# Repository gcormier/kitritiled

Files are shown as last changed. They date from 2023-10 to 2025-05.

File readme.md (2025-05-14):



# kitritiled
This is a copy of Ted Yapo's tritiled project from https://github.com/tedyapo/tritiled. It is based on the V3.1 design.
I did my best to reproduce the schematic, and optimize it for automated assembly as opposed to hand-assembly. As a result, it uses some slightly different parts, such as 0402 components when possible.

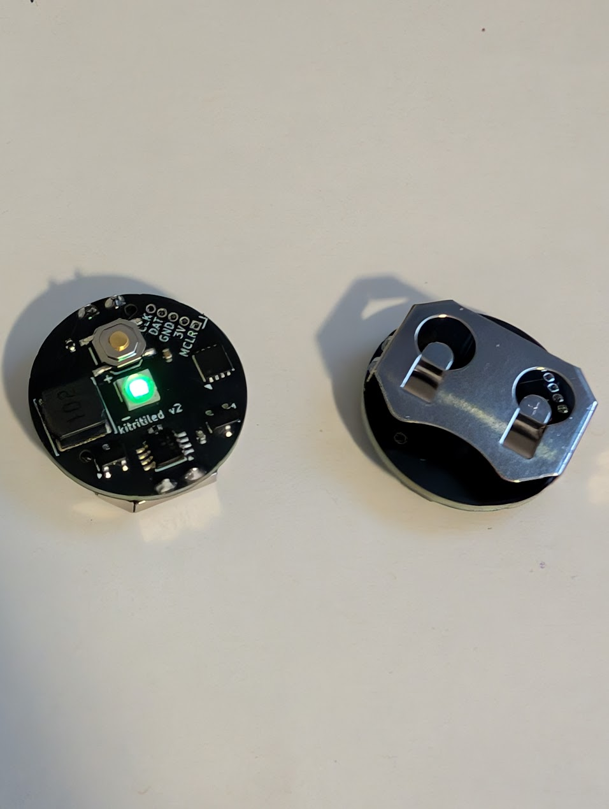
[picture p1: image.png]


## Firmware
kitritiled.hex is the firmware to flash. I lost track of the changes I made to the original firmware by Ted - if you use his v30 runtime selectable, it almost works, except the button doesn't seem to trigger the interrupt. It's been a few years since I looked at it, so I pulled the firmware off one of my v1 devices and
that's all I have unfortunately. `modes.h` is also changed slightly from his.

## Flashing
I use MPLAB IPE to flash the firmware with a MPLAB PICkit 5.

## Usage
The device has 10 power levels, and starts on the brightest setting.

When you first insert the battery, you have a 10 second window during which you can configure the power level.

This is done by pushing the button on the device. Once you hit the lowest power level, it will start back at the highest.

When you are done, leave it alone. It will blink the LED to indicate the power level. eg 1 blink for level 1, 2 blinks for level 2, etc.

It will do this three times, at which point it will then lock in at that power level and the button will no longer work.

If you want to change the power level, you need to remove the battery, and wait for the light to go out completely before repeating the above process.

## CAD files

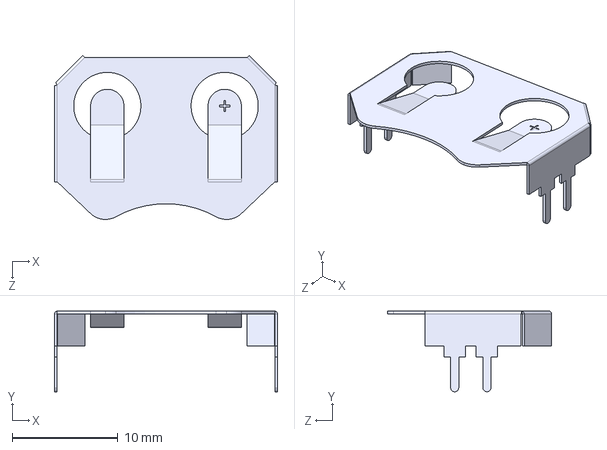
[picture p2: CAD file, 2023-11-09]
pcb/BAT-HLD-001-THM.step
21.1 x 7.62 x 15.5 mm

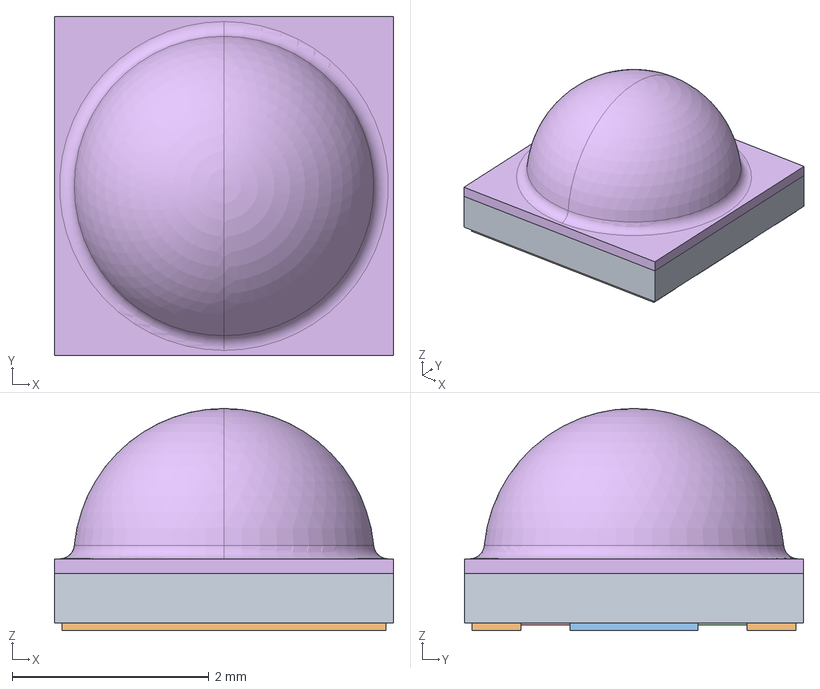
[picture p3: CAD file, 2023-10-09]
pcb/XLamp XP-E2 XP-G2.STEP
3.45 x 3.45 x 2.26 mm
2500-00565C
2500-00565C-BT
2500-00565C-SBN
2500-00565C-SB
2610-00066-DOME

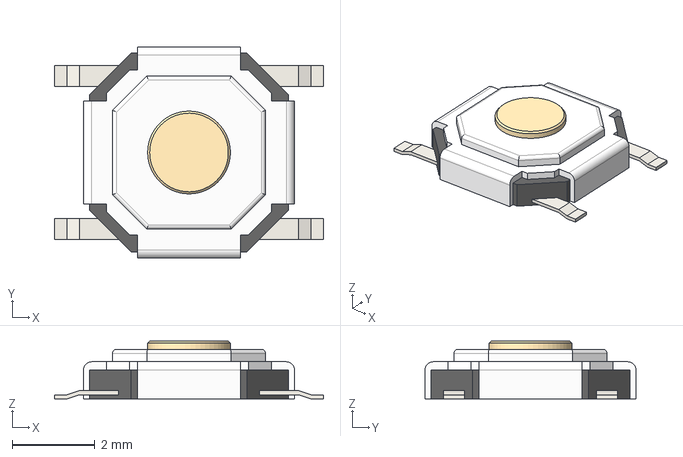
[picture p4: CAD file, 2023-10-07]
pcb/TS-1187A.step
6.50 x 5.10 x 1.40 mm

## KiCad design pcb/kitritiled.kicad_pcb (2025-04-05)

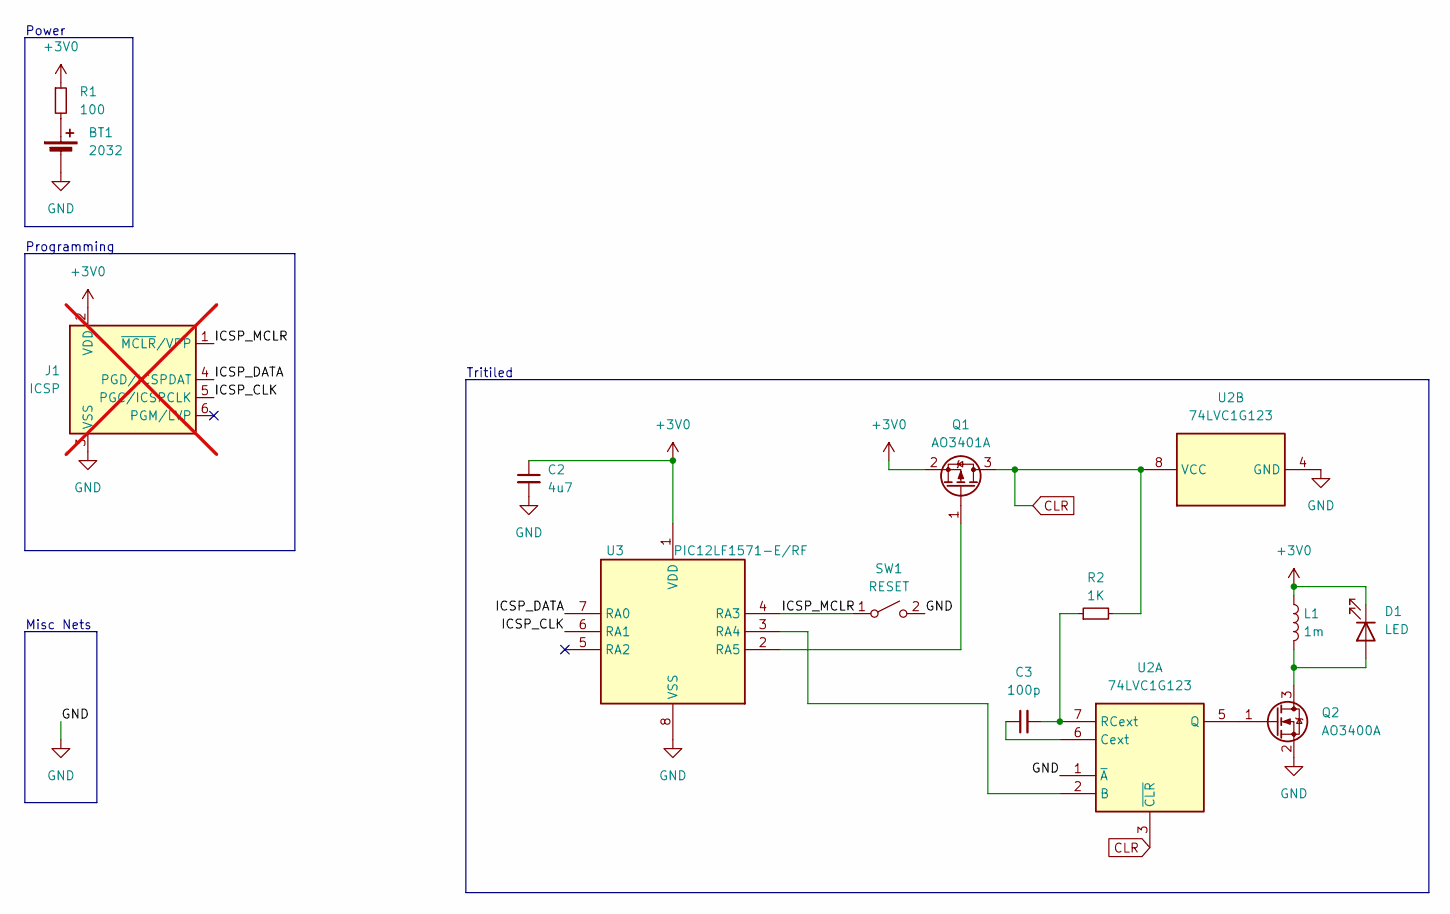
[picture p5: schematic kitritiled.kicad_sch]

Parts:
BT1: 2032; BAT_BAT-HLD-001-THM
C2: 4u7; C_0402_1005Metric; LCSC C23733
C3: 100p; C_0402_1005Metric; LCSC C1546
D1: LED; LED_Cree-XP; DIGIKEY XPEBGR-L1-0000-00F02
J1: ICSP; PinHeader_1x05_P1.27mm_Vertical; not fitted
L1: 1m; L_Sunlord_SWPA6028S; LCSC C133757
Q1: AO3401A; SOT-23; LCSC C15127
Q2: AO3400A; SOT-23; LCSC C20917
R1: 100; R_0402_1005Metric; LCSC C25076
R2: 1K; R_0402_1005Metric; LCSC C11702
SW1: RESET; SW_Push_1P1T_XKB_TS-1187A; LCSC C318884
U2: 74LVC1G123; TSSOP-8_3x3mm_P0.65mm; LCSC C513291
U3: PIC12LF1571-E/RF; DFN-8-1EP_3x3mm_P0.65mm_EP1.55x2.4mm; LCSC C635312

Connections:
+3V0: C2.1, D1.1 (K), J1.2 (VDD), L1.1, Q1.2 (S), R1.1, U3.1 (VDD)
/ICSP_CLK: J1.5 (PGC/ICSPCLK), U3.6 (RA1)
/ICSP_DATA: J1.4 (PGD/ICSPDAT), U3.7 (RA0)
/ICSP_MCLR: J1.1 (~MCLR/VPP), SW1.1 (A), U3.4 (RA3)
CLR: Q1.3 (D), R2.2, U2.3 (~CLR), U2.8 (VCC)
GND: BT1.2 (-), C2.2, J1.3 (VSS), Q2.2 (S), SW1.2 (B), U2.1 (~A), U2.4 (GND), U3.8 (VSS)
unnamed: BT1.1 (+), R1.2
unnamed: D1.2 (A), L1.2, Q2.3 (D)
unnamed: Q1.1 (G), U3.2 (RA5)
unnamed: Q2.1 (G), U2.5 (Q)
unnamed: U2.2 (B), U3.3 (RA4)
unnamed: C3.1, U2.6 (Cext)
unnamed: C3.2, R2.1, U2.7 (RCext)

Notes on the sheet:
Tritiled
Programming
Misc Nets
Power

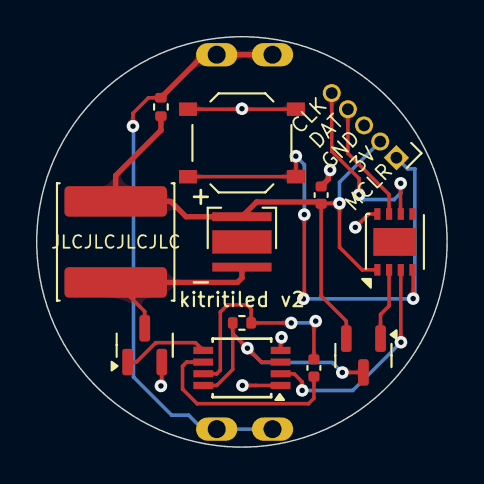
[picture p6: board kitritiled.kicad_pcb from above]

Board: 2 copper layers, 22.8 x 22.8 mm, 13 parts (1 on the bottom side), 13 nets.

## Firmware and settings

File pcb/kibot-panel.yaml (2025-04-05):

kibot:
  version: 1

preflight:
  check_zone_fills: true
  fill_zones: true

outputs:
  - name: 'panel'
    type: panelize
    options:
      title: '+ (Panel)'
      units: mm
      configs:
        - layout:
            rows: 2
            cols: 5
            space: 2.5mm
          tabs:
            type: fixed
            width: 5mm
          cuts:
            type: mousebites
            drill: 0.6mm
            spacing: 1mm
            offset: 0.0mm
            prolong: 0.5mm
          framing:
            type: frame
            width: 7mm
            space: 2.5mm
            fillet: 1mm
            mintotalheight: 70mm
            mintotalwidth: 70mm
          tooling:
            type: 4hole
            hoffset: 5mm
            voffset: 2.5mm
            size: 2mm
          fiducials:
            type: 4fid
            hoffset: 15mm
            voffset: 3.85mm
            coppersize: 1mm
            opening: 2mm
          text:
            type: simple
            text: JLCJLCJLCJLC
            anchor: mt
            voffset: 2.5
            hjustify: center
            vjustify: center
          text2:
            type: simple
            text: "{date} (<<hash>>)"
            anchor: mb
            voffset: -2.5
            hjustify: center
            vjustify: center
          post:
            refillzones: true
            millradius: 1mm
            origin: bl

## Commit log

2023-10-09 license and silkscreen
    [kitritiled.kicad_pcb]
2023-10-09 new 3d model
    [LED-XP-E2.stp, kitritiled.kicad_pcb]
2023-10-30 jlc pn
    [kitritiled.kicad_pcb, kitritiled.kicad_sch]
2023-10-30 fix part number
    [kitritiled.kicad_sch]
2023-11-09 holder change
    [BAT-HLD-001-THM.step, kitritiled.kicad_pcb, kitritiled.kicad_sch]
2023-11-12 panel filter
2023-11-12 filter on kibot
2023-11-12 remove filter
2023-12-28 attiny version
    [kitritiled.kicad_pcb, kitritiled.kicad_sch]
2025-04-05 pic updates
    [kitritiled.kicad_pcb, kitritiled.kicad_sch]
